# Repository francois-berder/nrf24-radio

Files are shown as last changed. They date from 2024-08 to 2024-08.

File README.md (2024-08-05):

# NRF24 RC radio

This project consists of a custom board for controlling RC models using a NRF24L01+ radio.

## Hardware

The hardware consists of a custom board featuring a PIC16F1829 and a NRF24L01+ module.
The board has the following interfaces:

- 4 slots for RC servos or motor controllers
- A serial port for communication
- An ISCP port for programming the PIC16F1829

Kicad files for the custom files are present in the `hardware` directory.

### BOM

| Components | References | Footprint | Quantity |
| --- | --- | --- | --- |
| NRF24L01+ | U3 | | 1 |
| PIC16F1829 | U2 | QFN (4x4x0.9 mm) | 1 |
| MPC1700 | U1 | SOT-23 | 1 |
| Capacitor 100nF | C2 | SMD 0402 | 1 |
| Capacitor 1uF | C1, C3 | SMD 0402 | 2 |
| Capacitor 10uF  | C4, C5 | SMD 0603 | 2 |
| Resistor 10k | R1 | SMD 0402 | 1 |

## Firmware

The firmware is written in C and peripheral drivers were generated using MPLAB code configurator. The NRF24 driver was ported from this [repository](https://github.com/nRF24/RF24).

The device can run in 3 modes:

- RC receiver: it receives data from the radio and uses it to control servos
- RX radio: it receives data from the radio and sends it on the serial port
- TX radio: data received from the serial port is sent over the radio

### Instructions for building and flashing firmware

Requirements:

- [xc8 compiler](https://www.microchip.com/en-us/tools-resources/develop/mplab-xc-compilers)
- make

You can either build the firmware by using MPLAB X IDE or run this command:

```sh
make -C radio-firmware
```

Flash the HEX file using a [PicKit3](https://www.microchip.com/en-us/development-tool/pg164130) or a [PicKit4](https://www.microchip.com/en-us/development-tool/pg164140) by connecting the programmer to the ISCP connector present on the board.

### Configuration

The configuration of the device is stored in the PIC16F1829 EEPROM.
The size of the EEPROM is 256 bytes but only a small is currently in use.

Here is the EEPROM map:

| Address | Description | Default value | Valid range |
| --- | --- | --- | --- |
| 0 | Magic value | 0xDE | N/A |
| 1 | Radio channel | 76 | 0 - 125 |
| 2 | Radio Datarate | 0 (250KPBS) | 0: 250KPBS, 1: 1MPBS, 2: 2MPBS |
| 3 |  Radio payload size | 32 | 1-32 |
| 4-9 | NRF24 pipe0 address | 1 | 0-2^48 |
| 10 | Servo 0 position | 128 | 0 - 255 |
| 11 | Servo 1 position | 128 | 0 - 255 |
| 12 | Servo 2 position | 128 | 0 - 255 |
| 13 | Servo 3 position | 128 | 0 - 255 |
| 14 | Servo 0 offset | 64 | 0 - 128 |
| 15 | Servo 1 offset | 64 | 0 - 128 |
| 16 | Servo 2 offset | 64 | 0 - 128 |
| 17 | Servo 3 offset | 64 | 0 - 128 |
| 18-255  | Unused | N/A | N/A |

To read and write the configuration of the device, use `scripts/config.py`.

### Serial protocol

The serial port is configured in the following way: 115200 baud, 1 stop bit, no parity bit.

Each command is one byte long followed by data.

| Command | Value | Description | data length |
| --- | ----- | --- | --- |
| WRITE_EEPROM | 0 | Write byte to EEPROM | 2 (address and data) |
| READ_EEPROM | 1 | Read byte from EEPROM | 1 (address) |
| REQ_FIRMWARE_VERSION | 2 | Request firmware version | 0 |
| FIRMWARE_VERSION | 3 | Firmware version | 2 (major and minor version) |
| SERVO_ENABLE | 4 | Send signals on servos | 0 |
| SERVO_DISABLE | 5 | Stop signals on servos | 0 |
| EEPROM_DATA | 6 |  Byte read from EEPROM | 1 |
| RADIO_DATA | 7 | Data read from NRF24 radio | 32 |
| GET_MODE | 8 | Request device mode | 0 |
| SET_MODE | 9 | Change device mode | 1 |
| MODE | 10 | Current device mode | 1 |
| RESET | 11 | Reset device | 0 |

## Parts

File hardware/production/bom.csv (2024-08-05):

Designator | Footprint | Quantity | Value | LCSC Part #
C1, C3 | 402 | 2 | 1uF, X7R
C2 | 402 | 1 | 100nF, X7R
C4, C5 | 603 | 2 | 10uF, X7R
J1 | PinSocket_1x02_P2.54mm_Vertical | 1 | Conn_01x02_Female
J2, J4, J5, J6, J7 | PinSocket_1x03_P2.54mm_Vertical | 5 | Conn_01x03_Male
J3 | PinSocket_1x06_P2.54mm_Vertical | 1 | Conn_PIC_ICSP_ICD
R1 | 402 | 1 | 10k
U1 | SOT-23 | 1 | MCP1700-3002E_SOT23
U2 | QFN-20-1EP_4x4mm_P0.5mm_EP2.5x2.5mm | 1 | PIC16F1829-IML

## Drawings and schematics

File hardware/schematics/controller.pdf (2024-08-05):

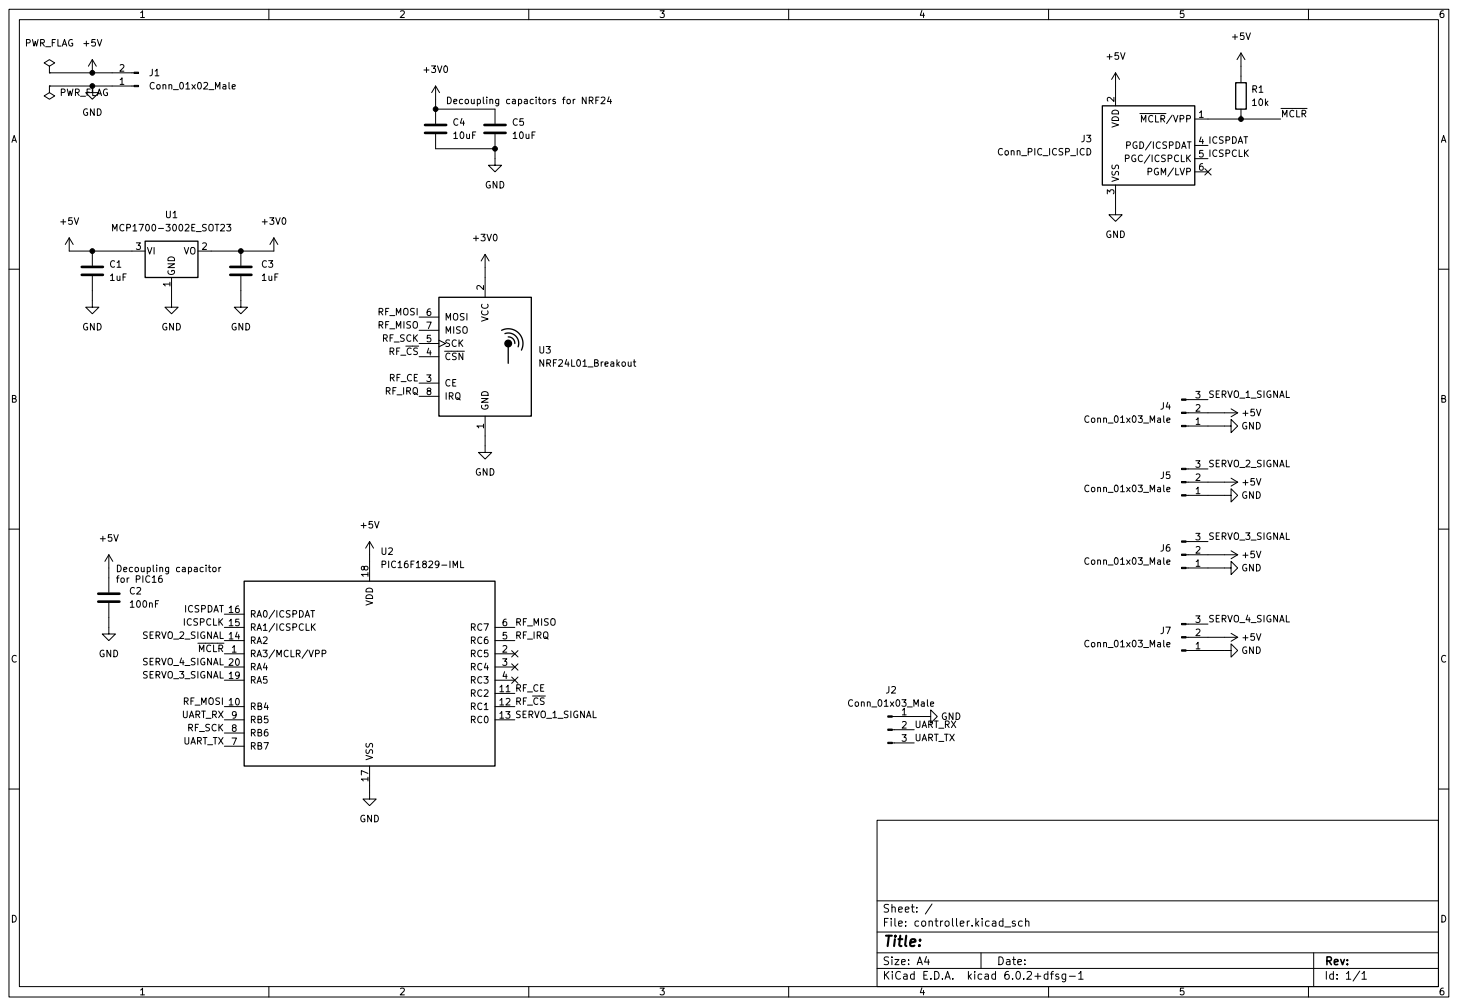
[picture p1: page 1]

3 PGD/ICSPDAT 4 PGC/ICSPCLK 5 PGM/LVP 6

2 CE 3 ~{CSN} 4 SCK 5 MOSI 6 MISO 7

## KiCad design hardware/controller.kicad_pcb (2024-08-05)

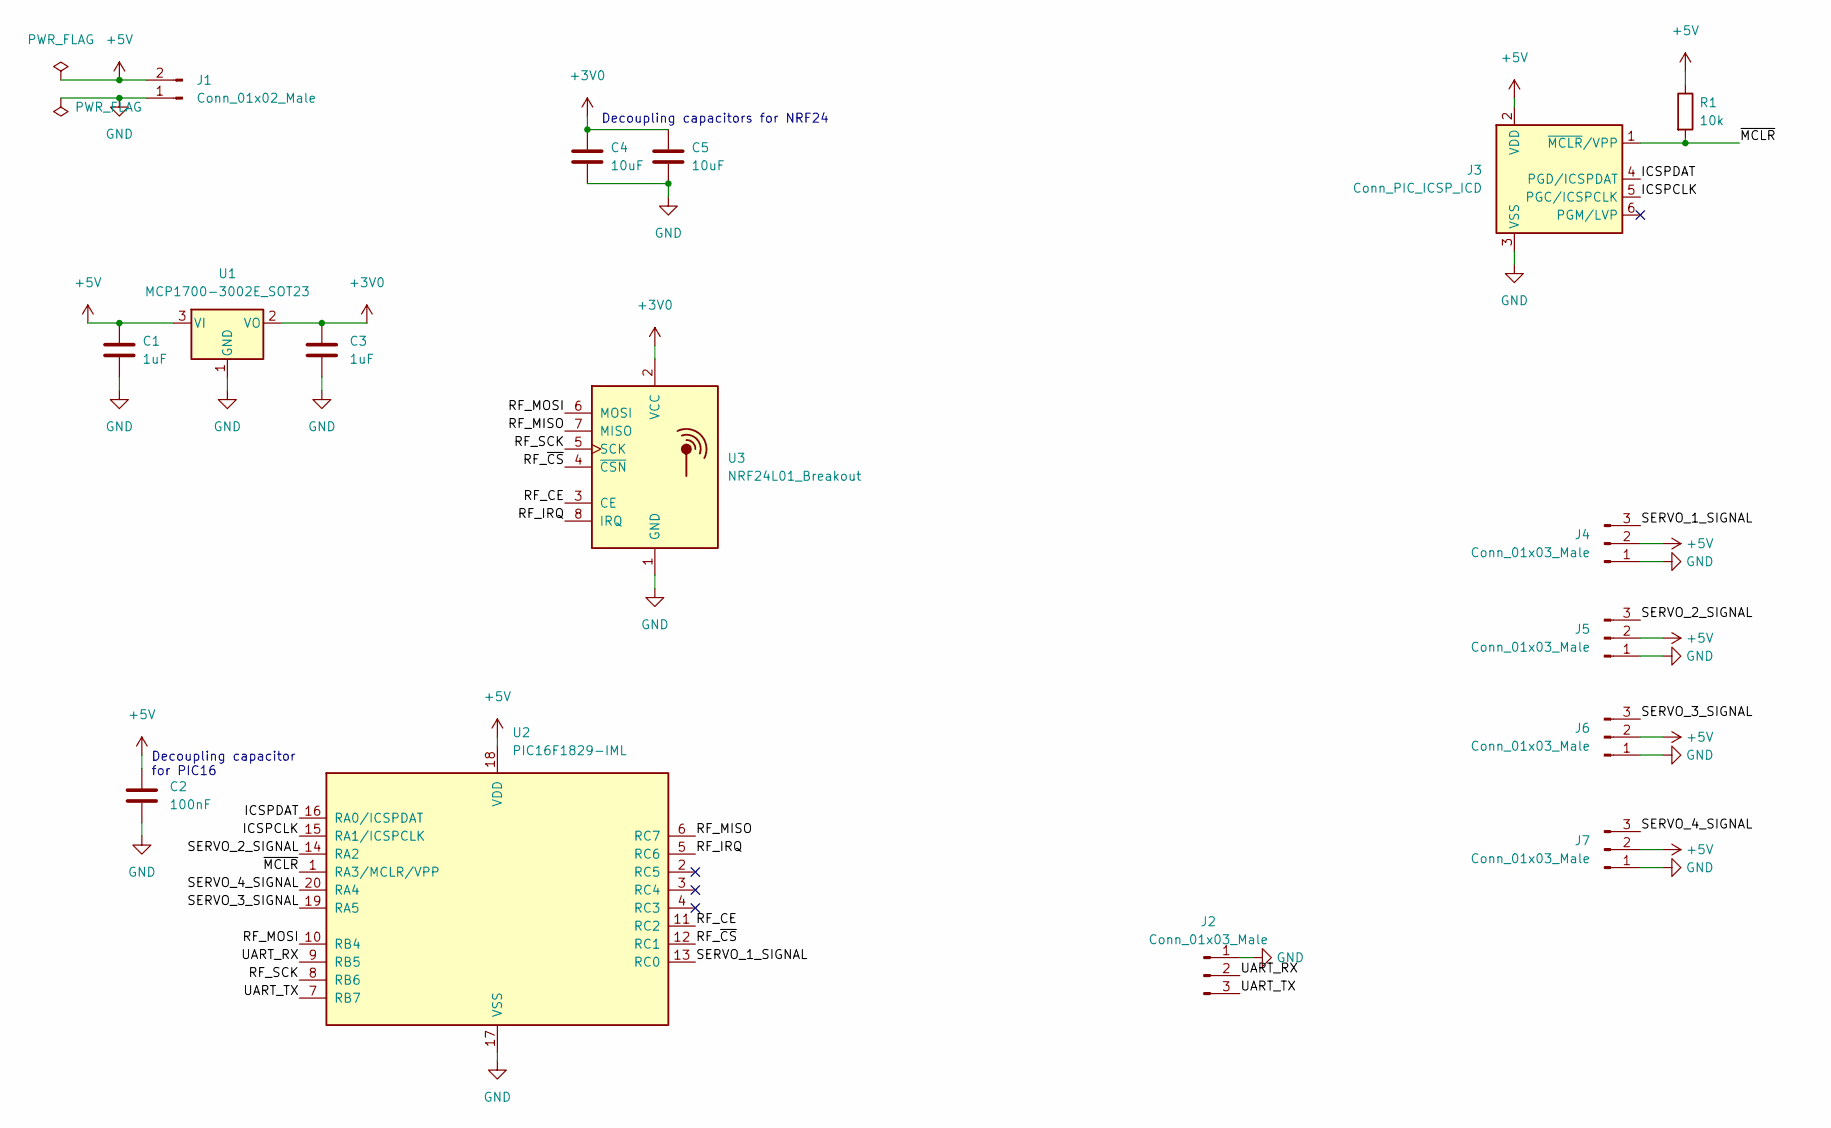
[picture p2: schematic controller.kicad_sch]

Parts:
C1, C3: 1uF; C_0402_1005Metric
C2: 100nF; C_0402_1005Metric
C4, C5: 10uF; C_0603_1608Metric
J1: Conn_01x02_Male
J2, J4, J5, J6, J7: Conn_01x03_Male; PinSocket_1x03_P2.54mm_Vertical
J3: Conn_PIC_ICSP_ICD; PinSocket_1x06_P2.54mm_Vertical
R1: 10k; R_0402_1005Metric
U1: MCP1700-3002E_SOT23; SOT-23
U2: PIC16F1829-IML; QFN-20-1EP_4x4mm_P0.5mm_EP2.5x2.5mm
U3: NRF24L01_Breakout; nRF24L01_Breakout

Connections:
+3V0: C3.1, C4.1, C5.1, U1.2 (VO), U3.2 (VCC)
+5V: C1.1, C2.1, J1.2, J3.2 (VDD), J4.2, J5.2, J6.2, J7.2, R1.1, U1.3 (VI), U2.18 (VDD)
/ICSPCLK: J3.5 (PGC/ICSPCLK), U2.15 (RA1/ICSPCLK)
/ICSPDAT: J3.4 (PGD/ICSPDAT), U2.16 (RA0/ICSPDAT)
/RF_CE: U2.11 (RC2), U3.3 (CE)
/RF_IRQ: U2.5 (RC6), U3.8 (IRQ)
/RF_MISO: U2.6 (RC7), U3.7 (MISO)
/RF_MOSI: U2.10 (RB4), U3.6 (MOSI)
/RF_SCK: U2.8 (RB6), U3.5 (SCK)
/RF_~CS: U2.12 (RC1), U3.4 (~CSN)
/SERVO_1_SIGNAL: J4.3, U2.13 (RC0)
/SERVO_2_SIGNAL: J5.3, U2.14 (RA2)
/SERVO_3_SIGNAL: J6.3, U2.19 (RA5)
/SERVO_4_SIGNAL: J7.3, U2.20 (RA4)
/UART_RX: J2.2, U2.9 (RB5)
/UART_TX: J2.3, U2.7 (RB7)
/~MCLR: J3.1 (~MCLR/VPP), R1.2, U2.1 (RA3/MCLR/VPP)
GND: C1.2, C2.2, C3.2, C4.2, C5.2, J1.1, J2.1, J3.3 (VSS), J4.1, J5.1, J6.1, J7.1, U1.1 (GND), U2.17 (VSS), U3.1 (GND)

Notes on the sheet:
Decoupling capacitor for PIC16
Decoupling capacitors for NRF24

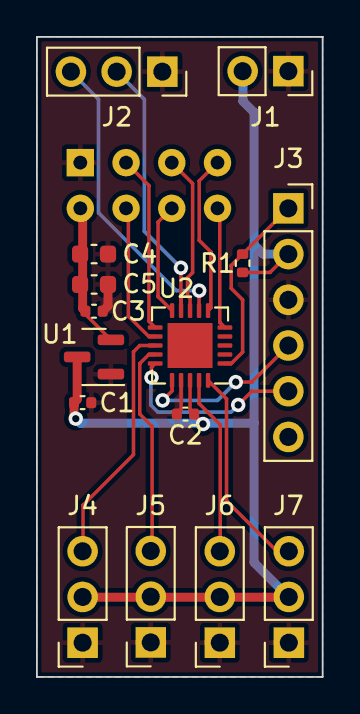
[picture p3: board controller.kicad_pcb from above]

Board: 2 copper layers, 15.9 x 35.6 mm, 16 parts (1 on the bottom side), 18 nets.

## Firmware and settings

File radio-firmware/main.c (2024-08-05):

/**
  Generated Main Source File

  Company:
    Microchip Technology Inc.

  File Name:
    main.c

  Summary:
    This is the main file generated using PIC10 / PIC12 / PIC16 / PIC18 MCUs

  Description:
    This header file provides implementations for driver APIs for all modules selected in the GUI.
    Generation Information :
        Product Revision  :  PIC10 / PIC12 / PIC16 / PIC18 MCUs - 1.81.8
        Device            :  PIC16F1829
        Driver Version    :  2.00
*/

/*
    (c) 2018 Microchip Technology Inc. and its subsidiaries. 
    
    Subject to your compliance with these terms, you may use Microchip software and any 
    derivatives exclusively with Microchip products. It is your responsibility to comply with third party 
    license terms applicable to your use of third party software (including open source software) that 
    may accompany Microchip software.
    
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
    IN NO EVENT WILL MICROCHIP BE LIABLE FOR ANY INDIRECT, SPECIAL, PUNITIVE, 
    INCIDENTAL OR CONSEQUENTIAL LOSS, DAMAGE, COST OR EXPENSE OF ANY KIND 
    WHATSOEVER RELATED TO THE SOFTWARE, HOWEVER CAUSED, EVEN IF MICROCHIP 
    HAS BEEN ADVISED OF THE POSSIBILITY OR THE DAMAGES ARE FORESEEABLE. TO 
    THE FULLEST EXTENT ALLOWED BY LAW, MICROCHIP'S TOTAL LIABILITY ON ALL 
    CLAIMS IN ANY WAY RELATED TO THIS SOFTWARE WILL NOT EXCEED THE AMOUNT 
    OF FEES, IF ANY, THAT YOU HAVE PAID DIRECTLY TO MICROCHIP FOR THIS 
    SOFTWARE.
*/

#include "config.h"
#include "mcc_generated_files/mcc.h"
#include "nrf24l01.h"
#include "serial.h"
#include "servo.h"
#include "version.h"

enum RADIO_MODE {
  RC_RECEIVER,
  RX_RADIO,
  TX_RADIO,
};
static enum RADIO_MODE mode = RC_RECEIVER;

static void enter_rc_receiver_mode(void)
{
    SERVO_Enable();
    NRF24L01_OpenReadingPipe(0, 0xE7E7E7E7E7E7E7LLU);
    NRF24L01_StartListening();
}

static void enter_rx_radio_mode(void)
{
    SERVO_Disable();
    NRF24L01_OpenReadingPipe(0, 0xE7E7E7E7E7E7E7LLU);
    NRF24L01_StartListening();
}

static void enter_tx_radio_mode(void)
{
    SERVO_Disable();
    NRF24L01_OpenWritingPipe(0xE7E7E7E7E7E7E7LLU);
    NRF24L01_StopListening();
}

static void change_mode(uint8_t new_mode)
{
    if (mode == new_mode) {
        return;
    }

    if (new_mode == RC_RECEIVER) {
        enter_rc_receiver_mode();
    } else if (new_mode == RX_RADIO) {
        enter_rx_radio_mode();
    } else if (new_mode == TX_RADIO) {
        enter_tx_radio_mode();
    } else {
        return;
    }

    mode = new_mode;
}

static void handle_serial_commands(void)
{
    struct serial_cmd_t cmd;
    while (SERIAL_Receive(&cmd)) {
        switch (cmd.id) {
        case WRITE_EEPROM:
            DATAEE_WriteByte(cmd.write_eeprom_data.addr, cmd.write_eeprom_data.data);
            break;
        case READ_EEPROM:
            cmd.id = EEPROM_DATA;
            cmd.eeprom_data.data = DATAEE_ReadByte(cmd.read_eeprom_data.addr);
            SERIAL_Send(&cmd);
            break;
        case REQ_FIRMWARE_VERSION:
            cmd.id = FIRMWARE_VERSION;
            cmd.firmware_version.major = FW_VERSION_MAJOR;
            cmd.firmware_version.minor = FW_VERSION_MINOR;
            SERIAL_Send(&cmd);
            break;
        case FIRMWARE_VERSION:
            /* Ignore */
            break;
        case START_SERVO:
            if (mode == RC_RECEIVER) {
                SERVO_Enable();
            }
            break;
        case STOP_SERVO:
            if (mode == RC_RECEIVER) {
                SERVO_Disable();
            }
            break;
        case EEPROM_DATA:
            /* Ignore */
            break;
        case RADIO_DATA:
            if (mode == TX_RADIO) {
                NRF24L01_Write(cmd.radio_data.data, sizeof(cmd.radio_data.data));
            }
            break;
        case SET_MODE:
            change_mode(cmd.set_mode.mode);
            break;
        case GET_MODE:
            cmd.id = MODE;
            cmd.mode.mode = mode;
            SERIAL_Send(&cmd);
            break;
        case MODE:
            /* Ignore */
            break;
        case RESET:
            asm("reset");
            while(1);
            break;
        }
    }
}

static void handle_radio(void)
{
    if (mode == RC_RECEIVER) {
        while (NRF24L01_AvailableData()) {
            uint8_t data[32];
            NRF24L01_Read(data, sizeof(data));
            SERVO_SetValues(data);
        }
    } else if (mode == RX_RADIO) {
        while (NRF24L01_AvailableData()) {
            uint8_t data[32];
            NRF24L01_Read(data, sizeof(data));

            struct serial_cmd_t cmd;
            cmd.id = RADIO_DATA;
            for (uint8_t i = 0; i < sizeof(data); ++i) {
                cmd.radio_data.data[i] = data[i];
            }
            SERIAL_Send(&cmd);
        }
    }
}

/*
                         Main application
 */
void main(void)
{
    // Initialize the device
    SYSTEM_Initialize();
    INTERRUPT_GlobalInterruptEnable();
    INTERRUPT_PeripheralInterruptEnable();

    CONFIG_Initialize();
    SERVO_Initialize();

    // TODO: Use settings from CONFIG
    NRF24L01_Initialize(76, NRF24_DATARATE_1MBPS);

    mode = RC_RECEIVER;
    enter_rc_receiver_mode();

    while (1) {
        SERIAL_Process();

        handle_serial_commands();
        handle_radio();
    }
}
/**
 End of File
*/

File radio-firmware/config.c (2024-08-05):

#include "config.h"
#include "mcc_generated_files/mcc.h"
#include "nrf24l01.h"
#include "servo.h"

// EEPROM configuration map
#define CONFIG_MAGIC_ADDR   (0x00)
#define RADIO_CHANNEL_ADDR (0x01)
#define RADIO_DATARATE_ADDR (0x02)
#define RADIO_PAYLOAD_SIZE (0x03)
#define RADIO_PIPE_ADDRESS (0x04)
#define SERVO_POSITION (0x0A)
#define SERVO_OFFSET (0x0E)

// Default values
#define CONFIG_MAGIC_VALUE (0xDE)
#define DEFAULT_RADIO_CHANNEL (76)
#define DEFAULT_RADIO_DATARATE (NRF24_DATARATE_1MBPS)
#define DEFAULT_RADIO_PAYLOAD_SIZE (32)
#define DEFAULT_RADIO_PIPE_ADDRESS (1)
#define DEFAULT_SERVO_POSITION (128)
#define DEFAULT_SERVO_OFFSET (64)

void CONFIG_Initialize(void)
{
    uint8_t magic = DATAEE_ReadByte(CONFIG_MAGIC_ADDR);
    if (magic != CONFIG_MAGIC_VALUE) {
        CONFIG_SetRadioChannel(DEFAULT_RADIO_CHANNEL);
        CONFIG_SetRadioDataRate(DEFAULT_RADIO_DATARATE);
        CONFIG_SetPayloadSize(DEFAULT_RADIO_PAYLOAD_SIZE);
        CONFIG_SetPipeAddress(DEFAULT_RADIO_PIPE_ADDRESS);
        for (uint8_t i = 0; i < SERVO_COUNT; ++i) {
            CONFIG_SetServoPosition(i, DEFAULT_SERVO_POSITION);
            CONFIG_SetServoOffset(i, DEFAULT_SERVO_OFFSET);
        }
        DATAEE_WriteByte(CONFIG_MAGIC_ADDR, CONFIG_MAGIC_VALUE);
    }
}

void CONFIG_SetRadioChannel(uint8_t channel)
{
    DATAEE_WriteByte(RADIO_CHANNEL_ADDR, channel);
}

uint8_t CONFIG_GetRadioChannel(void)
{
   return DATAEE_ReadByte(RADIO_CHANNEL_ADDR); 
}

void CONFIG_SetRadioDataRate(enum NRF24_DataRate datarate)
{
    DATAEE_WriteByte(RADIO_DATARATE_ADDR, datarate);
}

enum NRF24_DataRate CONFIG_GetRadioDataRate(void)
{
    return DATAEE_ReadByte(RADIO_DATARATE_ADDR);
}

void CONFIG_SetPayloadSize(uint8_t payload_size)
{
    DATAEE_WriteByte(RADIO_PAYLOAD_SIZE, payload_size);
}

uint8_t CONFIG_GetPayloadSize(void)
{
    return DATAEE_ReadByte(RADIO_PAYLOAD_SIZE);
}

void CONFIG_SetPipeAddress(uint64_t address)
{
    uint8_t *ptr = (uint8_t *)&address;
    uint8_t i;
    for (i = 0; i < 6; ++i) {
        DATAEE_WriteByte(RADIO_PIPE_ADDRESS + i, ptr[i]);
    }
}

uint64_t CONFIG_GetPipeAddress(void)
{
    uint64_t address = 0;
    uint8_t *ptr = (uint8_t *)&address;
    uint8_t i;
    for (i = 0; i < 6; ++i) {
        ptr[i] = DATAEE_ReadByte(RADIO_PIPE_ADDRESS + i);
    }
    return address;
}

void CONFIG_SetServoPosition(uint8_t index, uint8_t pos)
{
    if (index < SERVO_COUNT) {
        DATAEE_WriteByte(SERVO_POSITION + index, pos);
    }
}

uint8_t CONFIG_GetServoPosition(uint8_t index)
{
    if (index >= SERVO_COUNT) {
        return 0;
    }

    return DATAEE_ReadByte(SERVO_POSITION + index);
}

void CONFIG_SetServoOffset(uint8_t index, uint8_t offset)
{
    if (index < SERVO_COUNT) {
        DATAEE_WriteByte(SERVO_OFFSET + index, offset);
    }
}

uint8_t CONFIG_GetServoOffset(uint8_t index)
{
    if (index >= SERVO_COUNT) {
        return 0;
    }

    return DATAEE_ReadByte(SERVO_OFFSET + index);
}

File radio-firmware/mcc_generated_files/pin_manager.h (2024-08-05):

/**
  @Generated Pin Manager Header File

  @Company:
    Microchip Technology Inc.

  @File Name:
    pin_manager.h

  @Summary:
    This is the Pin Manager file generated using PIC10 / PIC12 / PIC16 / PIC18 MCUs

  @Description
    This header file provides APIs for driver for .
    Generation Information :
        Product Revision  :  PIC10 / PIC12 / PIC16 / PIC18 MCUs - 1.81.8
        Device            :  PIC16F1829
        Driver Version    :  2.11
    The generated drivers are tested against the following:
        Compiler          :  XC8 2.36 and above
        MPLAB 	          :  MPLAB X 6.00	
*/

/*
    (c) 2018 Microchip Technology Inc. and its subsidiaries. 
    
    Subject to your compliance with these terms, you may use Microchip software and any 
    derivatives exclusively with Microchip products. It is your responsibility to comply with third party 
    license terms applicable to your use of third party software (including open source software) that 
    may accompany Microchip software.
    
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
    IN NO EVENT WILL MICROCHIP BE LIABLE FOR ANY INDIRECT, SPECIAL, PUNITIVE, 
    INCIDENTAL OR CONSEQUENTIAL LOSS, DAMAGE, COST OR EXPENSE OF ANY KIND 
    WHATSOEVER RELATED TO THE SOFTWARE, HOWEVER CAUSED, EVEN IF MICROCHIP 
    HAS BEEN ADVISED OF THE POSSIBILITY OR THE DAMAGES ARE FORESEEABLE. TO 
    THE FULLEST EXTENT ALLOWED BY LAW, MICROCHIP'S TOTAL LIABILITY ON ALL 
    CLAIMS IN ANY WAY RELATED TO THIS SOFTWARE WILL NOT EXCEED THE AMOUNT 
    OF FEES, IF ANY, THAT YOU HAVE PAID DIRECTLY TO MICROCHIP FOR THIS 
    SOFTWARE.
*/

#ifndef PIN_MANAGER_H
#define PIN_MANAGER_H

/**
  Section: Included Files
*/

#include <xc.h>

#define INPUT   1
#define OUTPUT  0

#define HIGH    1
#define LOW     0

#define ANALOG      1
#define DIGITAL     0

#define PULL_UP_ENABLED      1
#define PULL_UP_DISABLED     0

// get/set SERVO_2_SIGNAL aliases
#define SERVO_2_SIGNAL_TRIS                 TRISAbits.TRISA2
#define SERVO_2_SIGNAL_LAT                  LATAbits.LATA2
#define SERVO_2_SIGNAL_PORT                 PORTAbits.RA2
#define SERVO_2_SIGNAL_WPU                  WPUAbits.WPUA2
#define SERVO_2_SIGNAL_ANS                  ANSELAbits.ANSA2
#define SERVO_2_SIGNAL_SetHigh()            do { LATAbits.LATA2 = 1; } while(0)
#define SERVO_2_SIGNAL_SetLow()             do { LATAbits.LATA2 = 0; } while(0)
#define SERVO_2_SIGNAL_Toggle()             do { LATAbits.LATA2 = ~LATAbits.LATA2; } while(0)
#define SERVO_2_SIGNAL_GetValue()           PORTAbits.RA2
#define SERVO_2_SIGNAL_SetDigitalInput()    do { TRISAbits.TRISA2 = 1; } while(0)
#define SERVO_2_SIGNAL_SetDigitalOutput()   do { TRISAbits.TRISA2 = 0; } while(0)
#define SERVO_2_SIGNAL_SetPullup()          do { WPUAbits.WPUA2 = 1; } while(0)
#define SERVO_2_SIGNAL_ResetPullup()        do { WPUAbits.WPUA2 = 0; } while(0)
#define SERVO_2_SIGNAL_SetAnalogMode()      do { ANSELAbits.ANSA2 = 1; } while(0)
#define SERVO_2_SIGNAL_SetDigitalMode()     do { ANSELAbits.ANSA2 = 0; } while(0)

// get/set SERVO_4_SIGNAL aliases
#define SERVO_4_SIGNAL_TRIS                 TRISAbits.TRISA4
#define SERVO_4_SIGNAL_LAT                  LATAbits.LATA4
#define SERVO_4_SIGNAL_PORT                 PORTAbits.RA4
#define SERVO_4_SIGNAL_WPU                  WPUAbits.WPUA4
#define SERVO_4_SIGNAL_ANS                  ANSELAbits.ANSA4
#define SERVO_4_SIGNAL_SetHigh()            do { LATAbits.LATA4 = 1; } while(0)
#define SERVO_4_SIGNAL_SetLow()             do { LATAbits.LATA4 = 0; } while(0)
#define SERVO_4_SIGNAL_Toggle()             do { LATAbits.LATA4 = ~LATAbits.LATA4; } while(0)
#define SERVO_4_SIGNAL_GetValue()           PORTAbits.RA4
#define SERVO_4_SIGNAL_SetDigitalInput()    do { TRISAbits.TRISA4 = 1; } while(0)
#define SERVO_4_SIGNAL_SetDigitalOutput()   do { TRISAbits.TRISA4 = 0; } while(0)
#define SERVO_4_SIGNAL_SetPullup()          do { WPUAbits.WPUA4 = 1; } while(0)
#define SERVO_4_SIGNAL_ResetPullup()        do { WPUAbits.WPUA4 = 0; } while(0)
#define SERVO_4_SIGNAL_SetAnalogMode()      do { ANSELAbits.ANSA4 = 1; } while(0)
#define SERVO_4_SIGNAL_SetDigitalMode()     do { ANSELAbits.ANSA4 = 0; } while(0)

// get/set SERVO_3_SIGNAL aliases
#define SERVO_3_SIGNAL_TRIS                 TRISAbits.TRISA5
#define SERVO_3_SIGNAL_LAT                  LATAbits.LATA5
#define SERVO_3_SIGNAL_PORT                 PORTAbits.RA5
#define SERVO_3_SIGNAL_WPU                  WPUAbits.WPUA5
#define SERVO_3_SIGNAL_SetHigh()            do { LATAbits.LATA5 = 1; } while(0)
#define SERVO_3_SIGNAL_SetLow()             do { LATAbits.LATA5 = 0; } while(0)
#define SERVO_3_SIGNAL_Toggle()             do { LATAbits.LATA5 = ~LATAbits.LATA5; } while(0)
#define SERVO_3_SIGNAL_GetValue()           PORTAbits.RA5
#define SERVO_3_SIGNAL_SetDigitalInput()    do { TRISAbits.TRISA5 = 1; } while(0)
#define SERVO_3_SIGNAL_SetDigitalOutput()   do { TRISAbits.TRISA5 = 0; } while(0)
#define SERVO_3_SIGNAL_SetPullup()          do { WPUAbits.WPUA5 = 1; } while(0)
#define SERVO_3_SIGNAL_ResetPullup()        do { WPUAbits.WPUA5 = 0; } while(0)

// get/set SOFTSPI_MOSI_IO aliases
#define SOFTSPI_MOSI_IO_TRIS                 TRISBbits.TRISB4
#define SOFTSPI_MOSI_IO_LAT                  LATBbits.LATB4
#define SOFTSPI_MOSI_IO_PORT                 PORTBbits.RB4
#define SOFTSPI_MOSI_IO_WPU                  WPUBbits.WPUB4
#define SOFTSPI_MOSI_IO_ANS                  ANSELBbits.ANSB4
#define SOFTSPI_MOSI_IO_SetHigh()            do { LATBbits.LATB4 = 1; } while(0)
#define SOFTSPI_MOSI_IO_SetLow()             do { LATBbits.LATB4 = 0; } while(0)
#define SOFTSPI_MOSI_IO_Toggle()             do { LATBbits.LATB4 = ~LATBbits.LATB4; } while(0)
#define SOFTSPI_MOSI_IO_GetValue()           PORTBbits.RB4
#define SOFTSPI_MOSI_IO_SetDigitalInput()    do { TRISBbits.TRISB4 = 1; } while(0)
#define SOFTSPI_MOSI_IO_SetDigitalOutput()   do { TRISBbits.TRISB4 = 0; } while(0)
#define SOFTSPI_MOSI_IO_SetPullup()          do { WPUBbits.WPUB4 = 1; } while(0)
#define SOFTSPI_MOSI_IO_ResetPullup()        do { WPUBbits.WPUB4 = 0; } while(0)
#define SOFTSPI_MOSI_IO_SetAnalogMode()      do { ANSELBbits.ANSB4 = 1; } while(0)
#define SOFTSPI_MOSI_IO_SetDigitalMode()     do { ANSELBbits.ANSB4 = 0; } while(0)

// get/set RB5 procedures
#define RB5_SetHigh()            do { LATBbits.LATB5 = 1; } while(0)
#define RB5_SetLow()             do { LATBbits.LATB5 = 0; } while(0)
#define RB5_Toggle()             do { LATBbits.LATB5 = ~LATBbits.LATB5; } while(0)
#define RB5_GetValue()              PORTBbits.RB5
#define RB5_SetDigitalInput()    do { TRISBbits.TRISB5 = 1; } while(0)
#define RB5_SetDigitalOutput()   do { TRISBbits.TRISB5 = 0; } while(0)
#define RB5_SetPullup()             do { WPUBbits.WPUB5 = 1; } while(0)
#define RB5_ResetPullup()           do { WPUBbits.WPUB5 = 0; } while(0)
#define RB5_SetAnalogMode()         do { ANSELBbits.ANSB5 = 1; } while(0)
#define RB5_SetDigitalMode()        do { ANSELBbits.ANSB5 = 0; } while(0)
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

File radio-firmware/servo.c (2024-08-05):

/*
 * File:   servo.c
 * Author: francois
 *
 * Created on March 24, 2023, 9:51 PM
 */


#include <xc.h>
#include "mcc_generated_files/mcc.h"
#include "servo.h"

#define SERVO_DEFAULT_VALUE (128)
#define SERVO_DEFAULT_OFFSET (64)
#define TMR2_1MS_PERIOD (124)
#define OFFSET_ZERO (64)

static volatile uint8_t values[SERVO_COUNT] = {
    SERVO_DEFAULT_VALUE,
    SERVO_DEFAULT_VALUE,
    SERVO_DEFAULT_VALUE,
    SERVO_DEFAULT_VALUE
};
static volatile uint8_t offsets[SERVO_COUNT] = {
    SERVO_DEFAULT_OFFSET,
    SERVO_DEFAULT_OFFSET,
    SERVO_DEFAULT_OFFSET,
    SERVO_DEFAULT_OFFSET,
};

static volatile uint8_t current_index = 0;

static void SERVO_Update(void);
static void SERVO_StopSignal(void);

void SERVO_Initialize(void)
{
    TMR1_SetInterruptHandler(SERVO_Update);
    TMR2_SetInterruptHandler(SERVO_StopSignal);
}

void SERVO_Enable(void)
{
    if (T1CONbits.TMR1ON) {
        return;
    }

    /* Wait for TMR2 to be stopped before starting TMR1 */
    while (T2CONbits.TMR2ON);

    current_index = 0;
    TMR1_Reload();
    TMR1_StartTimer();
}

void SERVO_Disable(void)
{
    TMR1_StopTimer();
    /* Note: do not stop TMR2 */
}

void SERVO_SetValue(uint8_t index, uint8_t value)
{
    if (index >= SERVO_COUNT)
        return;

    INTERRUPT_GlobalInterruptDisable();
    values[index] = value;
    INTERRUPT_GlobalInterruptEnable();
}

void SERVO_SetValues(uint8_t *new_values)
{
    INTERRUPT_GlobalInterruptDisable();
    values[0] = new_values[0];
    values[1] = new_values[1];
    values[2] = new_values[2];
    values[3] = new_values[3];
    INTERRUPT_GlobalInterruptEnable();
}

void SERVO_SetOffset(uint8_t index, uint8_t offset)
{
    if (index >= SERVO_COUNT)
        return;

    INTERRUPT_GlobalInterruptDisable();
    offsets[index] = offset;
    INTERRUPT_GlobalInterruptEnable();
}

void SERVO_SetOffsets(uint8_t *new_offsets)
{
    INTERRUPT_GlobalInterruptDisable();
    offsets[0] = new_offsets[0];
    offsets[1] = new_offsets[1];
    offsets[2] = new_offsets[2];
    offsets[3] = new_offsets[3];
    INTERRUPT_GlobalInterruptEnable();
}

// Called every 5ms
static void SERVO_Update(void)
{
    // Setup timer to raise interrupt after 1-2ms
    uint16_t val = TMR2_1MS_PERIOD;

    /* offset in range [-64, 64] */
    val += (offsets[current_index] / 2);
    val -= OFFSET_ZERO;

    val += (values[current_index] / 2);
    if (val >= UINT8_MAX) {
        val = UINT8_MAX;
    }

    TMR2_WriteTimer(0);
    TMR2_LoadPeriodRegister((uint8_t)val);
    TMR2_StartTimer();

    if (current_index == 0) {
        SERVO_1_SIGNAL_SetHigh();
    } else if (current_index == 1) {
        SERVO_2_SIGNAL_SetHigh();
    } else if (current_index == 2) {
        SERVO_3_SIGNAL_SetHigh();
    } else if (current_index == 3) {
        SERVO_4_SIGNAL_SetHigh();
    }
}

static void SERVO_StopSignal(void)
{
    SERVO_1_SIGNAL_SetLow();
    SERVO_2_SIGNAL_SetLow();
    SERVO_3_SIGNAL_SetLow();
    SERVO_4_SIGNAL_SetLow();
    TMR2_StopTimer();

    current_index++;
    if (current_index >= SERVO_COUNT) {
        current_index = 0;
    }
}
